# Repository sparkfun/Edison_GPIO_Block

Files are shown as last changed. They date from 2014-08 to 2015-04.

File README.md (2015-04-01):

SparkFun Edison GPIO Breakout
=============================

SparkFun Edison GPIO Breakout

[*SparkFun Edison GPIO Breakout(DEV-13038)*](https://www.sparkfun.com/products/13038)

The GPIO Breakout is a simple breakout board to bring the GPIO from the Intel Edison to the user.  Bread board friendly, the GPIO provides level-shifted access to all basic GPIO, PWM, and UART2. GPIO may be set to VSYS or 3.3v levels. The GPIO Breakout also provides access to all three power rails found on the Intel Edison.  3.3v, 1.8v, VSYS, and GND are accessable for bread board prototyping.

Repository Contents
-------------------
* **/Hardware** - All Eagle design files (.brd, .sch)
* **/Production** - TEst bed files and production panel files

License Information
-------------------

The hardware is released under [Creative Commons ShareAlike 4.0 International](https://creativecommons.org/licenses/by-sa/4.0/).
The code is beerware; if you see me (or any other SparkFun employee) at the local, and you've found our code helpful, please buy us a round!

Distributed as-is; no warranty is given.

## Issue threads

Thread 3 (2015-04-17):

Fritzing Component?

rwaldron, 2015-04-17:
Is there any chance of adding a fritzing component for this block?

ToniCorinne, 2015-04-17:
@HelloTechie Could we get this added in to the Fritzing repo?

HelloTechie, 2015-04-17:
Let me put it on the list! The main connector won't be usable, but the pins would be. Is that okay?

ToniCorinne, 2015-04-17:
I don't have any problem with that personally.

HelloTechie, 2015-04-17:
Awesome! Will post when completed. :)

HelloTechie, 2015-06-12:
Reorganized Fritzing and this part can be found here: https://github.com/sparkfun/Fritzing_Parts/commit/9dca354bc97bc871e642fe05f99ecdcb9647cb63

Sorry for the wait!

Closed 2015-06-12.

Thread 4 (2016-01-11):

Issues Enabling PWM Pins

mikekberg, 2016-01-11:
Is there any documentation regarding enabling the PWM pins? I've tried enabling the GPIO pin and PWM channel for the given pin and I'm not able to get PWM to work. Is there a requirement to set pin muxing like the ardino breakout board?

ShawnHymel, 2016-01-11:
If you are using MRAA, you can use the PWM class: http://iotdk.intel.com/docs/master/mraa/classmraa_1_1_pwm.html

mikekberg, 2016-01-11:
How can I push to these using echo's to the filesystem? I think I might just be missing the command to set the Pinmode to PWM. How is that done?

ShawnHymel, 2016-01-11:
You'll have to set the pin mode. Here's the best documentation I've found: http://www.emutexlabs.com/project/215-intel-edison-gpio-pin-multiplexing-guide

mikekberg, 2016-01-12:
I'm using the following:

echo mode1 > /sys/kernel/debug/gpio_debug/gpio12/current_pinmux
echo 0 > /sys/class/pwm/pwmchip0/export
echo 20000000 > /sys/class/pwm/pwmchip0/pwm0/period
echo 1080000 > /sys/class/pwm/pwmchip0/pwm0/duty_cycle
echo 1 > /sys/class/pwm/pwmchip0/pwm0/enable

this should in theory push a signal down the PWM0 channel. The previous post is documentation for the ardino breakout board which requires setting a number of pins to disable internal pull up resistors and set the direction of the pin. These pins are not present with the GPIO block (write errors when I try writing to them).

ShawnHymel, 2016-01-12:
I don't have an Edison in front of me right now to test this, but for now, see if [this article](https://theiotlearninginitiative.gitbooks.io/inteledison/content/documentation/PinMuxing.html) or [this post](https://communities.intel.com/thread/45986?start=0&) helps at all.

Also, how are you measuring PWM? The level shifters on the GPIO block have a hard time driving any amount of current (even 1 or 2 mA). Are you using a scope or connecting an LED, etc.?

mhord, 2016-01-12:
I've sweated through this myself, quite a bit. I feel like I eventually got it working but it's been awhile.

Your best bet is probably to [look at how Intel's mraa library](https://github.com/intel-iot-devkit/mraa/blob/master/src/pwm/pwm.c) does it; they're basically just constructing strings and pushing them into the files. I'm not saying it'll be easy; there are a lot of layers of conditionals and #define statements to dig through, but it will at least give you some idea of where you're headed.

mikekberg, 2016-01-12:
Thanks, That helps out a ton. I'll do some digging and see if I can post a solution for anyone else looking.

mikekberg, 2016-01-13:
So I've taken a look through the source and the code I posted above does work I was initially running on lower current and like @ShawnHymel commented about the current was too low to see an LED turn on.

Looks like the GPIO board follows the same mux'ing requirements the ardino breakout board uses. Thanks everyone!

AbhiKag, 2016-04-22:
Hey, I seem to be stuck at the same spot. Could you tell me how you worked around this (any config/hardware setup) ?

mikekberg, 2016-04-22:
Yes! I did get this going. I'll dig up the source code and post it. Are you looking to do it through bash shell or are you writing code? what language?

mikekberg, 2016-04-22:
This worked for me from bash

echo 12 > /sys/class/gpio/export
echo out > /sys/class/gpio/gpio12/direction
echo mode1 > /sys/kernel/debug/gpio_debug/gpio12/current_pinmux
echo 0 > /sys/class/pwm/pwmchip0/export
echo 20000000 > /sys/class/pwm/pwmchip0/pwm0/period
echo 1080000 > /sys/class/pwm/pwmchip0/pwm0/duty_cycle
echo 1 > /sys/class/pwm/pwmchip0/pwm0/enable

AbhiKag, 2016-04-22:
Thanks for the prompt response!
I will try this out.
For me, the sparkfun gpio board pwm pins are giving out a very low current (almost unusable).
Did you experience something similar, and if so, is there any solution?
I am open to any option, bash or c++! MRAA doesn't seem to be working though (maybe a platform recognition issue?) .

ShawnHymel, 2016-04-22:
In its normal operation, the TXB0108 (the level shifter on the GPIO Block) cannot source more than about 5 mA, which is barely enough to power an LED. I generally use a transistor to connect LEDs to the GPIO Block, like in [this example](https://learn.sparkfun.com/tutorials/installing-libmraa-on-ubilinux-for-edison#the-circuit).

Closed 2016-01-13.

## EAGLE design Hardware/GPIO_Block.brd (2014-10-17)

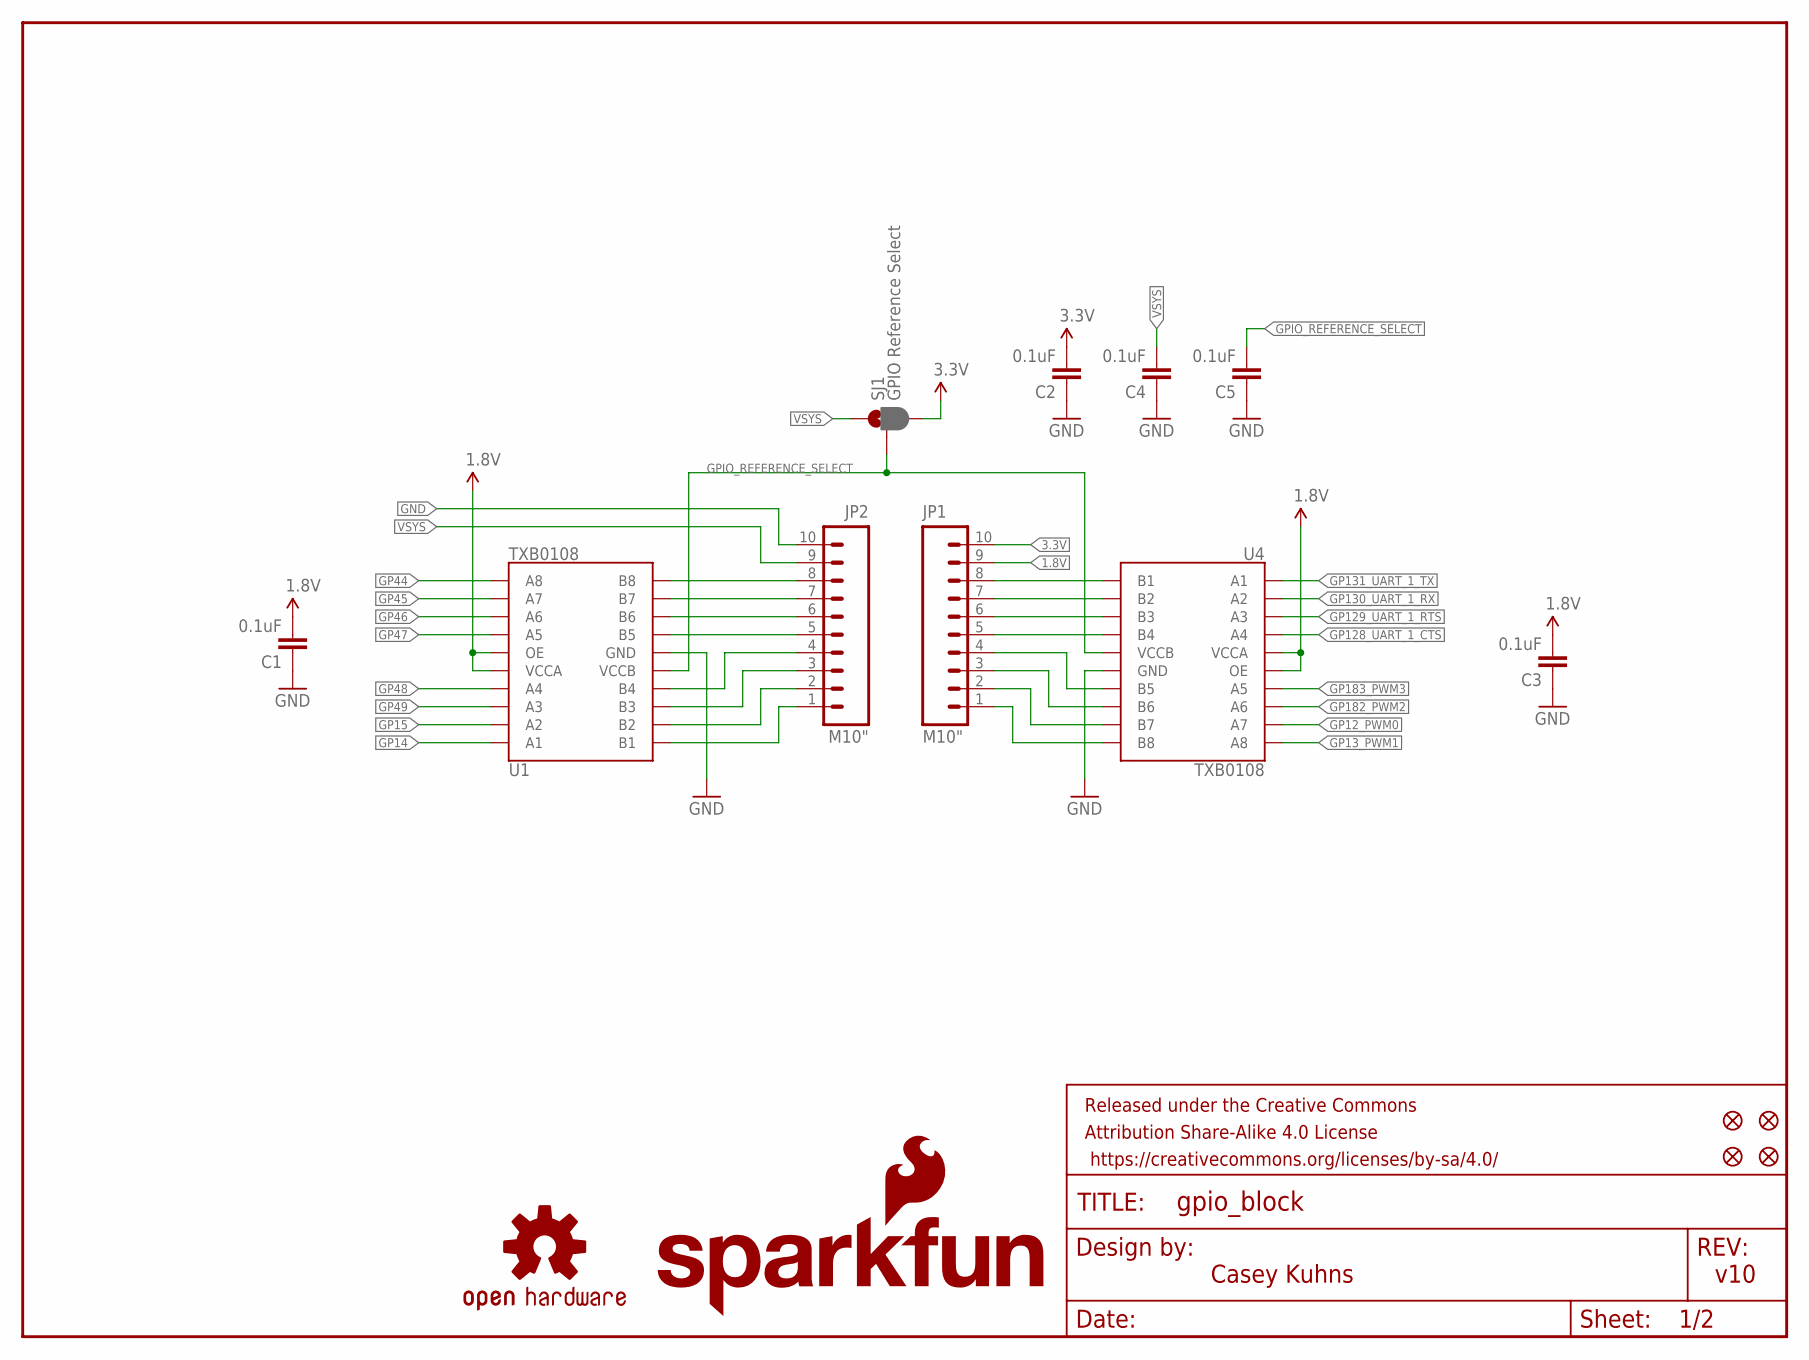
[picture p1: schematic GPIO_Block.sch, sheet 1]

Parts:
C1, C2, C3, C4, C5: 0.1uF; 0603-CAP
FID1, FID2, FID3, FID4: FIDUCIAL1X2; FIDUCIAL-1X2
FRAME1: FRAME-LETTER; CREATIVE_COMMONS
JP1, JP2: M10"; 1X10
LOGO1: OSHW-LOGOS; OSHW-LOGO-S
LOGO4: SFE_LOGO_NAME_FLAME.1_INCH; SFE_LOGO_NAME_FLAME_.1
SJ1: GPIO Reference Select; PAD-JUMPER-3-2OF3_NC_BY_PASTE_YES_SILK_FULL_BOX
U1, U4: TXB0108; UFDFN-20

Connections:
1.8V: C1.2, C3.2, JP1.9, U1.5 (VCCA), U1.6 (OE), U4.5 (VCCA), U4.6 (OE); also elsewhere on the board
3.3V: C2.2, JP1.10, SJ1.3; also elsewhere on the board
GND: C1.1, C2.1, C3.1, C4.1, C5.1, JP2.10, U1.15 (GND), U4.15 (GND); also elsewhere on the board
GP12_PWM0: U4.9 (A7); also elsewhere on the board
GP13_PWM1: U4.10 (A8); also elsewhere on the board
GP14: U1.1 (A1); also elsewhere on the board
GP15: U1.2 (A2); also elsewhere on the board
GP44: U1.10 (A8); also elsewhere on the board
GP45: U1.9 (A7); also elsewhere on the board
GP46: U1.8 (A6); also elsewhere on the board
GP47: U1.7 (A5); also elsewhere on the board
GP48: U1.4 (A4); also elsewhere on the board
GP49: U1.3 (A3); also elsewhere on the board
GP128_UART_1_CTS: U4.4 (A4); also elsewhere on the board
GP129_UART_1_RTS: U4.3 (A3); also elsewhere on the board
GP130_UART_1_RX: U4.2 (A2); also elsewhere on the board
GP131_UART_1_TX: U4.1 (A1); also elsewhere on the board
GP182_PWM2: U4.8 (A6); also elsewhere on the board
GP183_PWM3: U4.7 (A5); also elsewhere on the board
GPIO_REFERENCE_SELECT: C5.2, SJ1.2, U1.16 (VCCB), U4.16 (VCCB)
unnamed: JP2.8, U1.11 (B8)
unnamed: JP2.7, U1.12 (B7)
unnamed: JP2.6, U1.13 (B6)
unnamed: JP2.5, U1.14 (B5)
unnamed: JP2.4, U1.17 (B4)
unnamed: JP2.3, U1.18 (B3)
unnamed: JP2.2, U1.19 (B2)
unnamed: JP2.1, U1.20 (B1)
unnamed: JP1.4, U4.14 (B5)
unnamed: JP1.3, U4.13 (B6)
unnamed: JP1.2, U4.12 (B7)
unnamed: JP1.1, U4.11 (B8)
unnamed: JP1.5, U4.17 (B4)
unnamed: JP1.6, U4.18 (B3)
unnamed: JP1.7, U4.19 (B2)
unnamed: JP1.8, U4.20 (B1)
VSYS: C4.2, JP2.9, SJ1.1; also elsewhere on the board

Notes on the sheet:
v10
Casey Kuhns

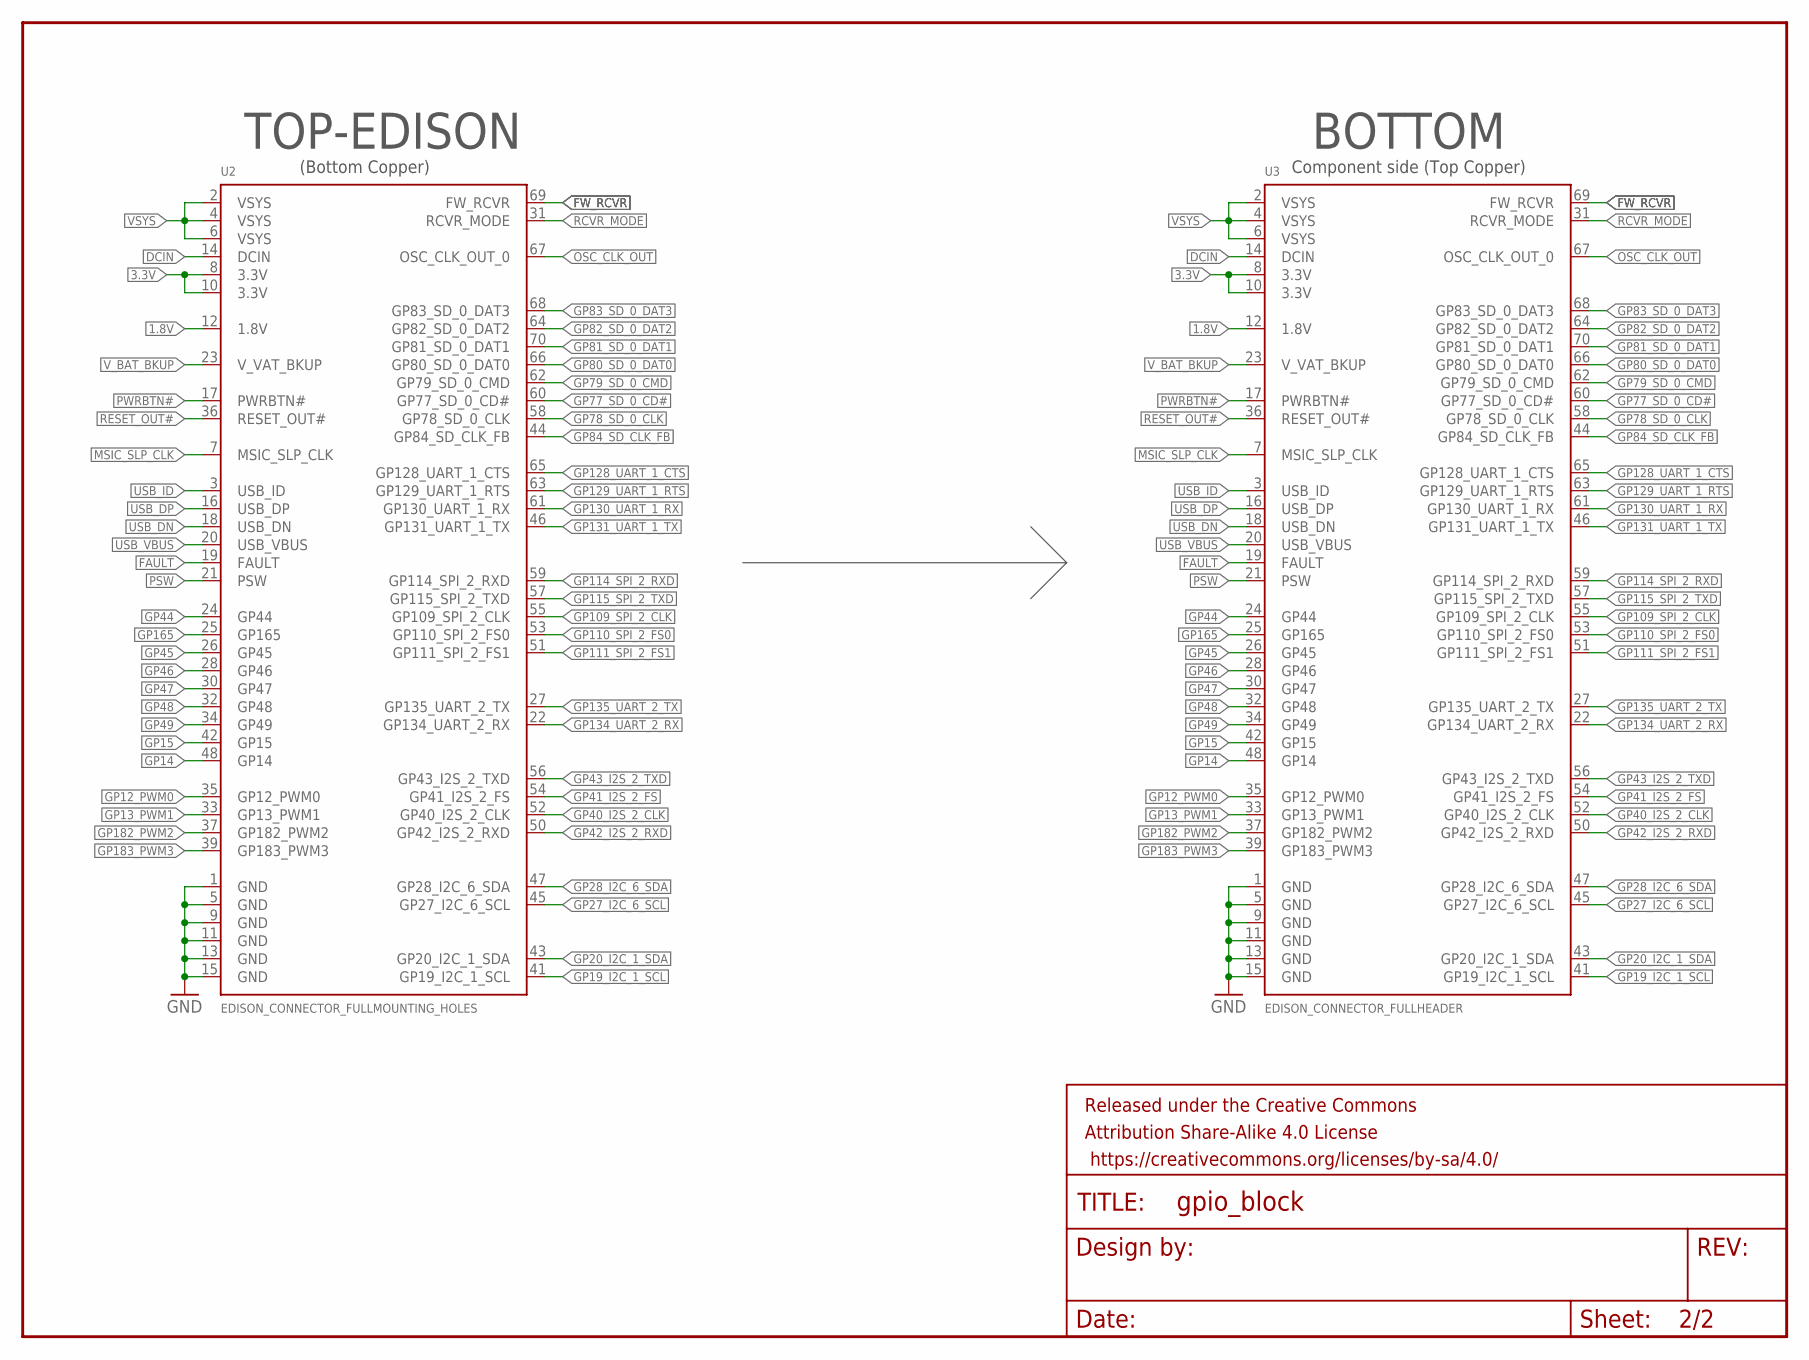
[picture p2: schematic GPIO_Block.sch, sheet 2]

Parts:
FRAME2: FRAME-LETTER; CREATIVE_COMMONS
U2: EDISON_CONNECTOR_FULLMOUNTING_HOLES; EDISON_DAUGHTER
U3: EDISON_CONNECTOR_FULLHEADER; DF40C-70DP-0.4(51)

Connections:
1.8V: U2.12 (1.8V), U3.12 (1.8V); also elsewhere on the board
3.3V: U2.8 (3.3V), U2.10 (3.3V), U3.8 (3.3V), U3.10 (3.3V); also elsewhere on the board
DCIN: U2.14 (DCIN), U3.14 (DCIN)
FAULT: U2.19 (FAULT), U3.19 (FAULT)
FW_RCVR: U2.69 (FW_RCVR), U3.69 (FW_RCVR)
GND: U2.1 (GND), U2.5 (GND), U2.9 (GND), U2.11 (GND), U2.13 (GND), U2.15 (GND), U3.1 (GND), U3.5 (GND), U3.9 (GND), U3.11 (GND), U3.13 (GND), U3.15 (GND); also elsewhere on the board
GP12_PWM0: U2.35 (GP12_PWM0), U3.35 (GP12_PWM0); also elsewhere on the board
GP13_PWM1: U2.33 (GP13_PWM1), U3.33 (GP13_PWM1); also elsewhere on the board
GP14: U2.48 (GP14), U3.48 (GP14); also elsewhere on the board
GP15: U2.42 (GP15), U3.42 (GP15); also elsewhere on the board
GP19_I2C_1_SCL: U2.41 (GP19_I2C_1_SCL), U3.41 (GP19_I2C_1_SCL)
GP20_I2C_1_SDA: U2.43 (GP20_I2C_1_SDA), U3.43 (GP20_I2C_1_SDA)
GP27_I2C_6_SCL: U2.45 (GP27_I2C_6_SCL), U3.45 (GP27_I2C_6_SCL)
GP28_I2C_6_SDA: U2.47 (GP28_I2C_6_SDA), U3.47 (GP28_I2C_6_SDA)
GP40_I2S_2_CLK: U2.52 (GP40_I2S_2_CLK), U3.52 (GP40_I2S_2_CLK)
GP41_I2S_2_FS: U2.54 (GP41_I2S_2_FS), U3.54 (GP41_I2S_2_FS)
GP42_I2S_2_RXD: U2.50 (GP42_I2S_2_RXD), U3.50 (GP42_I2S_2_RXD)
GP43_I2S_2_TXD: U2.56 (GP43_I2S_2_TXD), U3.56 (GP43_I2S_2_TXD)
GP44: U2.24 (GP44), U3.24 (GP44); also elsewhere on the board
GP45: U2.26 (GP45), U3.26 (GP45); also elsewhere on the board
GP46: U2.28 (GP46), U3.28 (GP46); also elsewhere on the board
GP47: U2.30 (GP47), U3.30 (GP47); also elsewhere on the board
GP48: U2.32 (GP48), U3.32 (GP48); also elsewhere on the board
GP49: U2.34 (GP49), U3.34 (GP49); also elsewhere on the board
GP77_SD_0_CD#: U2.60 (GP77_SD_0_CD#), U3.60 (GP77_SD_0_CD#)
GP78_SD_0_CLK: U2.58 (GP78_SD_0_CLK), U3.58 (GP78_SD_0_CLK)
GP79_SD_0_CMD: U2.62 (GP79_SD_0_CMD), U3.62 (GP79_SD_0_CMD)
GP80_SD_0_DAT0: U2.66 (GP80_SD_0_DAT0), U3.66 (GP80_SD_0_DAT0)
GP81_SD_0_DAT1: U2.70 (GP81_SD_0_DAT1), U3.70 (GP81_SD_0_DAT1)
GP82_SD_0_DAT2: U2.64 (GP82_SD_0_DAT2), U3.64 (GP82_SD_0_DAT2)
GP83_SD_0_DAT3: U2.68 (GP83_SD_0_DAT3), U3.68 (GP83_SD_0_DAT3)
GP84_SD_CLK_FB: U2.44 (GP84_SD_CLK_FB), U3.44 (GP84_SD_CLK_FB)
GP109_SPI_2_CLK: U2.55 (GP109_SPI_2_CLK), U3.55 (GP109_SPI_2_CLK)
GP110_SPI_2_FS0: U2.53 (GP110_SPI_2_FS0), U3.53 (GP110_SPI_2_FS0)
GP111_SPI_2_FS1: U2.51 (GP111_SPI_2_FS1), U3.51 (GP111_SPI_2_FS1)
GP114_SPI_2_RXD: U2.59 (GP114_SPI_2_RXD), U3.59 (GP114_SPI_2_RXD)
GP115_SPI_2_TXD: U2.57 (GP115_SPI_2_TXD), U3.57 (GP115_SPI_2_TXD)
GP128_UART_1_CTS: U2.65 (GP128_UART_1_CTS), U3.65 (GP128_UART_1_CTS); also elsewhere on the board
GP129_UART_1_RTS: U2.63 (GP129_UART_1_RTS), U3.63 (GP129_UART_1_RTS); also elsewhere on the board
GP130_UART_1_RX: U2.61 (GP130_UART_1_RX), U3.61 (GP130_UART_1_RX); also elsewhere on the board
GP131_UART_1_TX: U2.46 (GP131_UART_1_TX), U3.46 (GP131_UART_1_TX); also elsewhere on the board
GP134_UART_2_RX: U2.22 (GP134_UART_2_RX), U3.22 (GP134_UART_2_RX)
GP135_UART_2_TX: U2.27 (GP135_UART_2_TX), U3.27 (GP135_UART_2_TX)
GP165: U2.25 (GP165), U3.25 (GP165)
GP182_PWM2: U2.37 (GP182_PWM2), U3.37 (GP182_PWM2); also elsewhere on the board
GP183_PWM3: U2.39 (GP183_PWM3), U3.39 (GP183_PWM3); also elsewhere on the board
MSIC_SLP_CLK: U2.7 (MSIC_SLP_CLK), U3.7 (MSIC_SLP_CLK)
OSC_CLK_OUT: U2.67 (OSC_CLK_OUT_0), U3.67 (OSC_CLK_OUT_0)
PSW: U2.21 (PSW), U3.21 (PSW)
PWRBTN#: U2.17 (PWRBTN#), U3.17 (PWRBTN#)
RCVR_MODE: U2.31 (RCVR_MODE), U3.31 (RCVR_MODE)
RESET_OUT#: U2.36 (RESET_OUT#), U3.36 (RESET_OUT#)
USB_DN: U2.18 (USB_DN), U3.18 (USB_DN)
USB_DP: U2.16 (USB_DP), U3.16 (USB_DP)
USB_ID: U2.3 (USB_ID), U3.3 (USB_ID)
USB_VBUS: U2.20 (USB_VBUS), U3.20 (USB_VBUS)
VSYS: U2.2 (VSYS), U2.4 (VSYS), U2.6 (VSYS), U3.2 (VSYS), U3.4 (VSYS), U3.6 (VSYS); also elsewhere on the board
V_BAT_BKUP: U2.23 (V_VAT_BKUP), U3.23 (V_VAT_BKUP)

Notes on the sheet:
TOP-EDISON
BOTTOM
Component side (Top Copper)
(Bottom Copper)

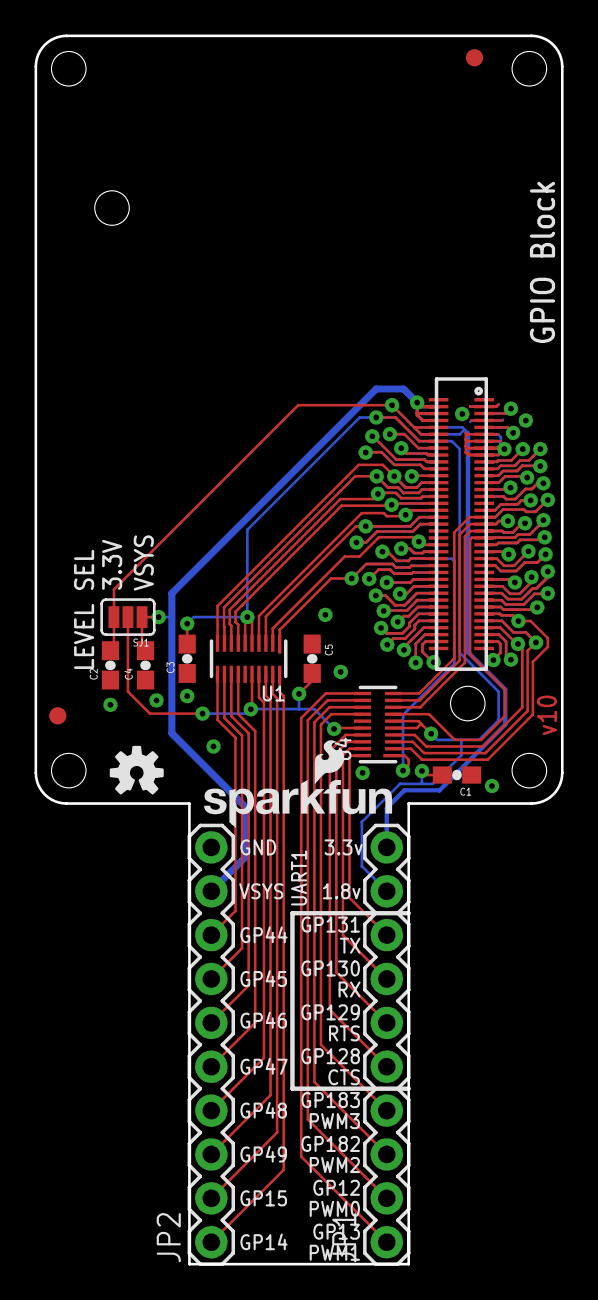
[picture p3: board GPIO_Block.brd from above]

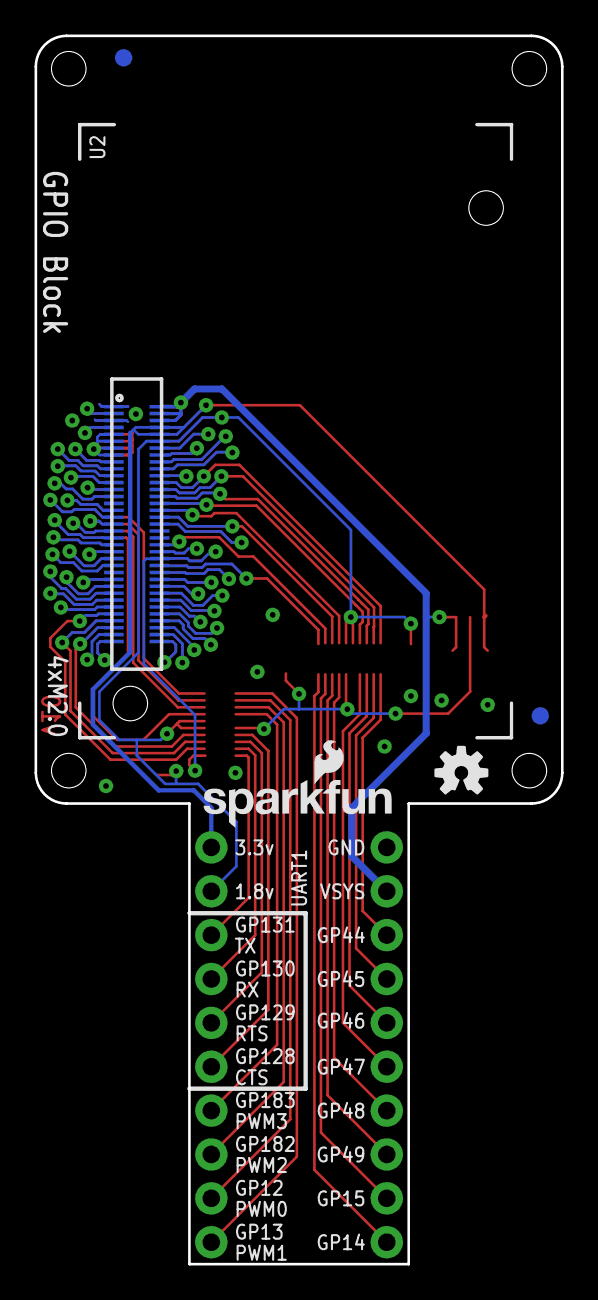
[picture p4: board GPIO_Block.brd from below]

Board: 2 copper layers, 30.5 x 71.1 mm, 22 parts (6 on the bottom side), 75 nets.

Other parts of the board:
LOGO2: OSHW-LOGOS; OSHW-LOGO-S
LOGO3: SFE_LOGO_NAME_FLAME.1_INCH; SFE_LOGO_NAME_FLAME_.1

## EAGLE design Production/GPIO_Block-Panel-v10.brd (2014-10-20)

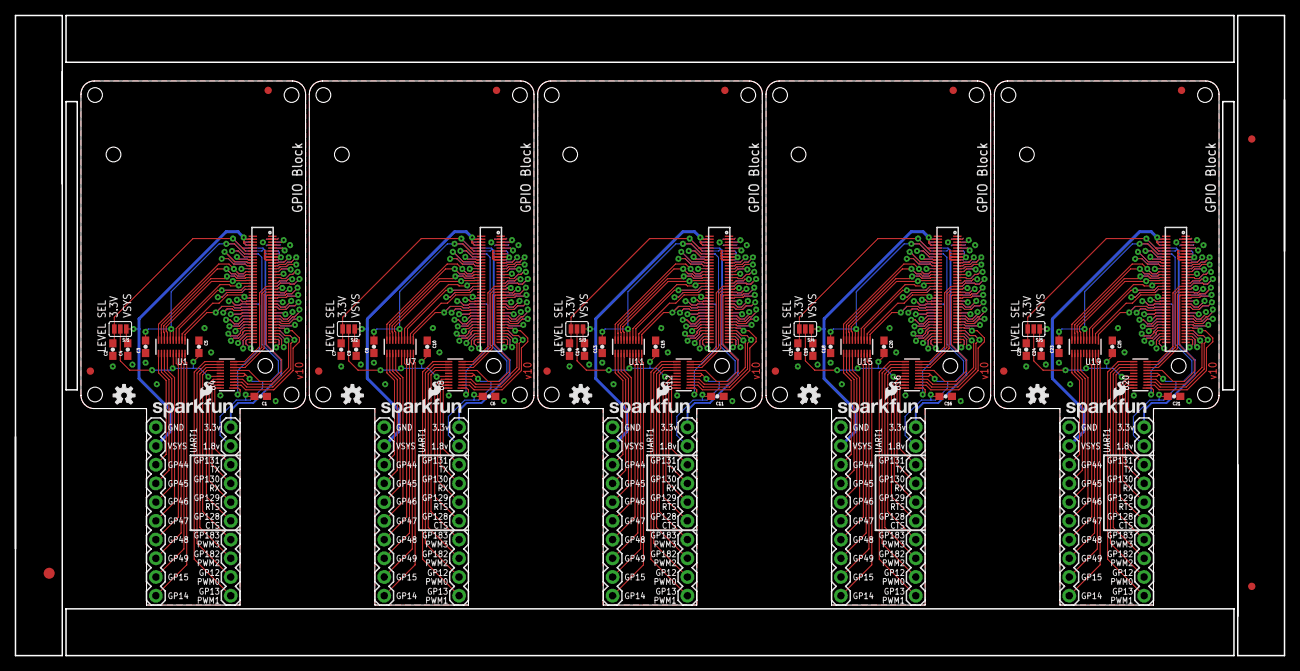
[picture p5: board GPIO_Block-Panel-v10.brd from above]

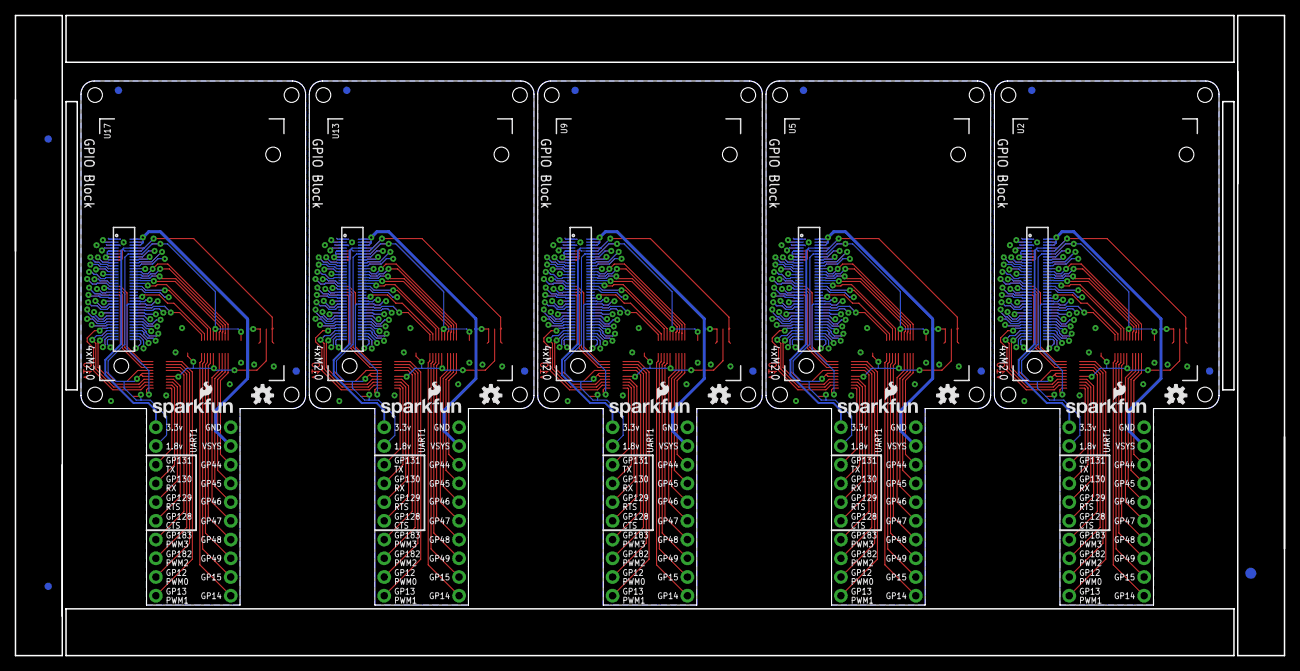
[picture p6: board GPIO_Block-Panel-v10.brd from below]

Board: 2 copper layers, 172.2 x 86.9 mm, 106 parts (33 on the bottom side), 375 nets.

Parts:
C1, C2, C3, C4, C5, C6, C7, C8, C9, C10, C11, C12, C13, C14, C15, C16, C17, C18, C19, C20, C21, C22, C23, C24, C25: 0.1uF; 0603-CAP
E$1, E$2: FIDUCIAL-1.5X3
E$3, E$4, E$5, E$6: FIDUCIAL-1X2
FID1, FID2, FID3, FID4, FID5, FID6, FID7, FID8, FID9, FID10, FID11, FID12, FID13, FID14, FID15, FID16, FID17, FID18, FID19, FID20: FIDUCIAL1X2; FIDUCIAL-1X2
JP1, JP2, JP3, JP4, JP5, JP6, JP7, JP8, JP9, JP10: M10"; 1X10
LOGO1, LOGO2, LOGO5, LOGO7, LOGO9, LOGO11, LOGO13, LOGO15, LOGO17, LOGO19: OSHW-LOGOS; OSHW-LOGO-S
LOGO3, LOGO4, LOGO6, LOGO8, LOGO10, LOGO12, LOGO14, LOGO16, LOGO18, LOGO20: SFE_LOGO_NAME_FLAME.1_INCH; SFE_LOGO_NAME_FLAME_.1
SJ1, SJ2, SJ3, SJ4, SJ5: GPIO Reference Select; PAD-JUMPER-3-2OF3_NC_BY_PASTE_YES_SILK_FULL_BOX
U1, U4, U7, U8, U11, U12, U15, U16, U19, U20: TXB0108; UFDFN-20
U2, U5, U9, U13, U17: EDISON_CONNECTOR_FULLMOUNTING_HOLES; EDISON_DAUGHTER
U3, U6, U10, U14, U18: EDISON_CONNECTOR_FULLHEADER; DF40C-70DP-0.4(51)

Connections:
1.8V: C1.2, C3.2, JP1.9, U1.5, U1.6, U2.12, U3.12, U4.5, U4.6
1.8V1: C6.2, C8.2, JP3.9, U5.12, U6.12, U7.5, U7.6, U8.5, U8.6
1.8V2: C11.2, C13.2, JP5.9, U9.12, U10.12, U11.5, U11.6, U12.5, U12.6
1.8V3: C16.2, C18.2, JP7.9, U13.12, U14.12, U15.5, U15.6, U16.5, U16.6
1.8V4: C21.2, C23.2, JP9.9, U17.12, U18.12, U19.5, U19.6, U20.5, U20.6
3.3V: C2.2, JP1.10, SJ1.3, U2.8, U2.10, U3.8, U3.10
3.3V1: C7.2, JP3.10, SJ2.3, U5.8, U5.10, U6.8, U6.10
3.3V2: C12.2, JP5.10, SJ3.3, U9.8, U9.10, U10.8, U10.10
3.3V3: C17.2, JP7.10, SJ4.3, U13.8, U13.10, U14.8, U14.10
3.3V4: C22.2, JP9.10, SJ5.3, U17.8, U17.10, U18.8, U18.10
DCIN: U2.14, U3.14
DCIN1: U5.14, U6.14
DCIN2: U9.14, U10.14
DCIN3: U13.14, U14.14
DCIN4: U17.14, U18.14
FAULT: U2.19, U3.19
FAULT1: U5.19, U6.19
FAULT2: U9.19, U10.19
FAULT3: U13.19, U14.19
FAULT4: U17.19, U18.19
FW_RCVR: U2.69, U3.69
FW_RCVR1: U5.69, U6.69
FW_RCVR2: U9.69, U10.69
FW_RCVR3: U13.69, U14.69
FW_RCVR4: U17.69, U18.69
GND: C1.1, C2.1, C3.1, C4.1, C5.1, JP2.10, U1.15, U2.1, U2.5, U2.9, U2.11, U2.13, U2.15, U3.1, U3.5, U3.9, U3.11, U3.13, U3.15, U4.15
GND1: C6.1, C7.1, C8.1, C9.1, C10.1, JP4.10, U5.1, U5.5, U5.9, U5.11, U5.13, U5.15, U6.1, U6.5, U6.9, U6.11, U6.13, U6.15, U7.15, U8.15
GND2: C11.1, C12.1, C13.1, C14.1, C15.1, JP6.10, U9.1, U9.5, U9.9, U9.11, U9.13, U9.15, U10.1, U10.5, U10.9, U10.11, U10.13, U10.15, U11.15, U12.15
GND3: C16.1, C17.1, C18.1, C19.1, C20.1, JP8.10, U13.1, U13.5, U13.9, U13.11, U13.13, U13.15, U14.1, U14.5, U14.9, U14.11, U14.13, U14.15, U15.15, U16.15
GND4: C21.1, C22.1, C23.1, C24.1, C25.1, JP10.10, U17.1, U17.5, U17.9, U17.11, U17.13, U17.15, U18.1, U18.5, U18.9, U18.11, U18.13, U18.15, U19.15, U20.15
GP1: U5.48, U6.48, U7.1
GP2: U5.42, U6.42, U7.2
GP3: U5.34, U6.34, U7.3
GP4: U5.32, U6.32, U7.4
GP5: U5.30, U6.30, U7.7
GP6: U5.28, U6.28, U7.8
GP7: U5.26, U6.26, U7.9
GP8: U5.25, U6.25
GP9: U5.24, U6.24, U7.10
GP10: U9.48, U10.48, U11.1
GP11: U9.42, U10.42, U11.2
GP12: U9.34, U10.34, U11.3
GP12_PWM0: U2.35, U3.35, U4.9
GP12_PWM1: U5.35, U6.35, U8.9
GP12_PWM2: U9.35, U10.35, U12.9
GP12_PWM3: U13.35, U14.35, U16.9
GP12_PWM4: U17.35, U18.35, U20.9
GP13: U9.32, U10.32, U11.4
GP13_PWM1: U2.33, U3.33, U4.10
GP13_PWM2: U5.33, U6.33, U8.10
GP13_PWM3: U9.33, U10.33, U12.10
GP13_PWM4: U13.33, U14.33, U16.10
GP13_PWM5: U17.33, U18.33, U20.10
GP14: U1.1, U2.48, U3.48
GP15: U1.2, U2.42, U3.42
GP16: U9.30, U10.30, U11.7
GP17: U9.28, U10.28, U11.8
GP18: U9.26, U10.26, U11.9
GP19: U9.25, U10.25
GP19_I2C_1_SCL: U2.41, U3.41
GP19_I2C_1_SCL1: U5.41, U6.41
GP19_I2C_1_SCL2: U9.41, U10.41
GP19_I2C_1_SCL3: U13.41, U14.41
GP19_I2C_1_SCL4: U17.41, U18.41
GP20: U9.24, U10.24, U11.10
GP20_I2C_1_SDA: U2.43, U3.43
GP20_I2C_1_SDA1: U5.43, U6.43
GP20_I2C_1_SDA2: U9.43, U10.43
GP20_I2C_1_SDA3: U13.43, U14.43
GP20_I2C_1_SDA4: U17.43, U18.43
GP21: U13.48, U14.48, U15.1
GP22: U13.42, U14.42, U15.2
GP23: U13.34, U14.34, U15.3
GP24: U13.32, U14.32, U15.4
GP25: U13.30, U14.30, U15.7
GP26: U13.28, U14.28, U15.8
GP27: U13.26, U14.26, U15.9
GP27_I2C_6_SCL: U2.45, U3.45
GP27_I2C_6_SCL1: U5.45, U6.45
GP27_I2C_6_SCL2: U9.45, U10.45
GP27_I2C_6_SCL3: U13.45, U14.45
GP27_I2C_6_SCL4: U17.45, U18.45
GP28: U13.25, U14.25
GP28_I2C_6_SDA: U2.47, U3.47
GP28_I2C_6_SDA1: U5.47, U6.47
GP28_I2C_6_SDA2: U9.47, U10.47
GP28_I2C_6_SDA3: U13.47, U14.47
GP28_I2C_6_SDA4: U17.47, U18.47
GP29: U13.24, U14.24, U15.10
GP30: U17.48, U18.48, U19.1
GP31: U17.42, U18.42, U19.2
GP32: U17.34, U18.34, U19.3
GP33: U17.32, U18.32, U19.4
GP34: U17.30, U18.30, U19.7
GP35: U17.28, U18.28, U19.8
GP36: U17.26, U18.26, U19.9
GP37: U17.25, U18.25
GP38: U17.24, U18.24, U19.10
GP40_I2S_2_CLK: U2.52, U3.52
GP40_I2S_2_CLK1: U5.52, U6.52
GP40_I2S_2_CLK2: U9.52, U10.52
GP40_I2S_2_CLK3: U13.52, U14.52
GP40_I2S_2_CLK4: U17.52, U18.52
GP41_I2S_2_FS: U2.54, U3.54
GP41_I2S_2_FS1: U5.54, U6.54
GP41_I2S_2_FS2: U9.54, U10.54
GP41_I2S_2_FS3: U13.54, U14.54
GP41_I2S_2_FS4: U17.54, U18.54
GP42_I2S_2_RXD: U2.50, U3.50
GP42_I2S_2_RXD1: U5.50, U6.50
GP42_I2S_2_RXD2: U9.50, U10.50
GP42_I2S_2_RXD3: U13.50, U14.50
GP42_I2S_2_RXD4: U17.50, U18.50
GP43_I2S_2_TXD: U2.56, U3.56
GP43_I2S_2_TXD1: U5.56, U6.56
GP43_I2S_2_TXD2: U9.56, U10.56
GP43_I2S_2_TXD3: U13.56, U14.56
GP43_I2S_2_TXD4: U17.56, U18.56
GP44: U1.10, U2.24, U3.24
GP45: U1.9, U2.26, U3.26
GP46: U1.8, U2.28, U3.28
GP47: U1.7, U2.30, U3.30
GP48: U1.4, U2.32, U3.32
GP49: U1.3, U2.34, U3.34
GP77_SD_0_CD#: U2.60, U3.60
GP77_SD_0_CD#1: U5.60, U6.60
GP77_SD_0_CD#2: U9.60, U10.60
GP77_SD_0_CD#3: U13.60, U14.60
GP77_SD_0_CD#4: U17.60, U18.60
GP78_SD_0_CLK: U2.58, U3.58
GP78_SD_0_CLK1: U5.58, U6.58
GP78_SD_0_CLK2: U9.58, U10.58
GP78_SD_0_CLK3: U13.58, U14.58
GP78_SD_0_CLK4: U17.58, U18.58
GP79_SD_0_CMD: U2.62, U3.62
GP79_SD_0_CMD1: U5.62, U6.62
GP79_SD_0_CMD2: U9.62, U10.62
GP79_SD_0_CMD3: U13.62, U14.62
GP79_SD_0_CMD4: U17.62, U18.62
GP80_SD_0_DAT0: U2.66, U3.66
GP80_SD_0_DAT1: U5.66, U6.66
GP80_SD_0_DAT2: U9.66, U10.66
GP80_SD_0_DAT3: U13.66, U14.66
GP80_SD_0_DAT4: U17.66, U18.66
GP81_SD_0_DAT1: U2.70, U3.70
GP81_SD_0_DAT2: U5.70, U6.70
GP81_SD_0_DAT3: U9.70, U10.70
GP81_SD_0_DAT4: U13.70, U14.70
GP81_SD_0_DAT5: U17.70, U18.70
GP82_SD_0_DAT1: U5.64, U6.64
GP82_SD_0_DAT2: U2.64, U3.64
GP82_SD_0_DAT3: U9.64, U10.64
GP82_SD_0_DAT4: U13.64, U14.64
GP82_SD_0_DAT5: U17.64, U18.64
GP83_SD_0_DAT1: U5.68, U6.68
GP83_SD_0_DAT2: U9.68, U10.68
GP83_SD_0_DAT3: U2.68, U3.68
GP83_SD_0_DAT4: U13.68, U14.68
GP83_SD_0_DAT5: U17.68, U18.68
GP84_SD_CLK_FB: U2.44, U3.44
GP84_SD_CLK_FB1: U5.44, U6.44
GP84_SD_CLK_FB2: U9.44, U10.44
GP84_SD_CLK_FB3: U13.44, U14.44
GP84_SD_CLK_FB4: U17.44, U18.44
GP109_SPI_2_CLK: U2.55, U3.55
GP109_SPI_2_CLK1: U5.55, U6.55
GP109_SPI_2_CLK2: U9.55, U10.55
GP109_SPI_2_CLK3: U13.55, U14.55
GP109_SPI_2_CLK4: U17.55, U18.55
GP110_SPI_2_FS0: U2.53, U3.53
GP110_SPI_2_FS1: U5.53, U6.53
GP110_SPI_2_FS2: U9.53, U10.53
GP110_SPI_2_FS3: U13.53, U14.53
GP110_SPI_2_FS4: U17.53, U18.53
GP111_SPI_2_FS1: U2.51, U3.51
GP111_SPI_2_FS2: U5.51, U6.51
GP111_SPI_2_FS3: U9.51, U10.51
GP111_SPI_2_FS4: U13.51, U14.51
GP111_SPI_2_FS5: U17.51, U18.51
GP114_SPI_2_RXD: U2.59, U3.59
GP114_SPI_2_RXD1: U5.59, U6.59
GP114_SPI_2_RXD2: U9.59, U10.59
GP114_SPI_2_RXD3: U13.59, U14.59
GP114_SPI_2_RXD4: U17.59, U18.59
GP115_SPI_2_TXD: U2.57, U3.57
GP115_SPI_2_TXD1: U5.57, U6.57
GP115_SPI_2_TXD2: U9.57, U10.57
GP115_SPI_2_TXD3: U13.57, U14.57
GP115_SPI_2_TXD4: U17.57, U18.57
GP128_UART_1_CTS: U2.65, U3.65, U4.4
GP128_UART_1_CTS1: U5.65, U6.65, U8.4
GP128_UART_1_CTS2: U9.65, U10.65, U12.4
GP128_UART_1_CTS3: U13.65, U14.65, U16.4
GP128_UART_1_CTS4: U17.65, U18.65, U20.4
GP129_UART_1_RTS: U2.63, U3.63, U4.3
GP129_UART_1_RTS1: U5.63, U6.63, U8.3
GP129_UART_1_RTS2: U9.63, U10.63, U12.3
GP129_UART_1_RTS3: U13.63, U14.63, U16.3
GP129_UART_1_RTS4: U17.63, U18.63, U20.3
GP130_UART_1_RX: U2.61, U3.61, U4.2
GP130_UART_1_RX1: U5.61, U6.61, U8.2
GP130_UART_1_RX2: U9.61, U10.61, U12.2
GP130_UART_1_RX3: U13.61, U14.61, U16.2
GP130_UART_1_RX4: U17.61, U18.61, U20.2
GP131_UART_1_TX: U2.46, U3.46, U4.1
GP131_UART_1_TX1: U5.46, U6.46, U8.1
GP131_UART_1_TX2: U9.46, U10.46, U12.1
GP131_UART_1_TX3: U13.46, U14.46, U16.1
GP131_UART_1_TX4: U17.46, U18.46, U20.1
GP134_UART_2_RX: U2.22, U3.22
GP134_UART_2_RX1: U5.22, U6.22
GP134_UART_2_RX2: U9.22, U10.22
GP134_UART_2_RX3: U13.22, U14.22
GP134_UART_2_RX4: U17.22, U18.22
GP135_UART_2_TX: U2.27, U3.27
GP135_UART_2_TX1: U5.27, U6.27
GP135_UART_2_TX2: U9.27, U10.27
GP135_UART_2_TX3: U13.27, U14.27
GP135_UART_2_TX4: U17.27, U18.27
GP165: U2.25, U3.25
GP182_PWM1: U5.37, U6.37, U8.8
GP182_PWM2: U2.37, U3.37, U4.8
GP182_PWM3: U9.37, U10.37, U12.8
GP182_PWM4: U13.37, U14.37, U16.8
GP182_PWM5: U17.37, U18.37, U20.8
GP183_PWM1: U5.39, U6.39, U8.7
GP183_PWM2: U9.39, U10.39, U12.7
GP183_PWM3: U2.39, U3.39, U4.7
GP183_PWM4: U13.39, U14.39, U16.7
GP183_PWM5: U17.39, U18.39, U20.7
GPIO_REFERENCE_SELECT: C5.2, SJ1.2, U1.16, U4.16
GPIO_REFERENCE_SELECT1: C10.2, SJ2.2, U7.16, U8.16
GPIO_REFERENCE_SELECT2: C15.2, SJ3.2, U11.16, U12.16
GPIO_REFERENCE_SELECT3: C20.2, SJ4.2, U15.16, U16.16
GPIO_REFERENCE_SELECT4: C25.2, SJ5.2, U19.16, U20.16
MSIC_SLP_CLK: U2.7, U3.7
MSIC_SLP_CLK1: U5.7, U6.7
MSIC_SLP_CLK2: U9.7, U10.7
MSIC_SLP_CLK3: U13.7, U14.7
MSIC_SLP_CLK4: U17.7, U18.7
unnamed: JP2.8, U1.11
unnamed: JP2.7, U1.12
unnamed: JP2.6, U1.13
unnamed: JP2.5, U1.14
unnamed: JP2.4, U1.17
unnamed: JP2.3, U1.18
unnamed: JP2.2, U1.19
unnamed: JP2.1, U1.20
unnamed: JP4.8, U7.11
unnamed: JP4.7, U7.12
unnamed: JP1.4, U4.14
unnamed: JP1.3, U4.13
unnamed: JP1.2, U4.12
unnamed: JP1.1, U4.11
unnamed: JP1.5, U4.17
unnamed: JP1.6, U4.18
unnamed: JP1.7, U4.19
unnamed: JP1.8, U4.20
unnamed: JP4.6, U7.13
unnamed: JP4.5, U7.14
unnamed: JP4.4, U7.17
unnamed: JP4.3, U7.18
unnamed: JP4.2, U7.19
unnamed: JP4.1, U7.20
unnamed: JP3.5, U8.17
unnamed: JP3.6, U8.18
unnamed: JP3.7, U8.19
unnamed: JP3.8, U8.20
unnamed: JP3.4, U8.14
unnamed: JP3.3, U8.13
unnamed: JP3.2, U8.12
unnamed: JP3.1, U8.11
unnamed: JP6.8, U11.11
unnamed: JP6.7, U11.12
unnamed: JP6.6, U11.13
unnamed: JP6.5, U11.14
unnamed: JP6.4, U11.17
unnamed: JP6.3, U11.18
unnamed: JP6.2, U11.19
unnamed: JP6.1, U11.20
unnamed: JP5.5, U12.17
unnamed: JP5.6, U12.18
unnamed: JP5.7, U12.19
unnamed: JP5.8, U12.20
unnamed: JP5.4, U12.14
unnamed: JP5.3, U12.13
unnamed: JP5.2, U12.12
unnamed: JP5.1, U12.11
unnamed: JP8.8, U15.11
unnamed: JP8.7, U15.12
unnamed: JP8.6, U15.13
unnamed: JP8.5, U15.14
unnamed: JP8.4, U15.17
unnamed: JP8.3, U15.18
unnamed: JP8.2, U15.19
unnamed: JP8.1, U15.20
unnamed: JP7.5, U16.17
unnamed: JP7.6, U16.18
unnamed: JP7.7, U16.19
unnamed: JP7.8, U16.20
unnamed: JP7.4, U16.14
unnamed: JP7.3, U16.13
unnamed: JP7.2, U16.12
unnamed: JP7.1, U16.11
unnamed: JP10.8, U19.11
unnamed: JP10.7, U19.12
unnamed: JP10.6, U19.13
unnamed: JP10.5, U19.14
unnamed: JP10.4, U19.17
unnamed: JP10.3, U19.18
unnamed: JP10.2, U19.19
unnamed: JP10.1, U19.20
unnamed: JP9.5, U20.17
unnamed: JP9.6, U20.18
unnamed: JP9.7, U20.19
unnamed: JP9.8, U20.20
unnamed: JP9.4, U20.14
unnamed: JP9.3, U20.13
unnamed: JP9.2, U20.12
unnamed: JP9.1, U20.11
OSC_CLK_OUT: U2.67, U3.67
OSC_CLK_OUT1: U5.67, U6.67
OSC_CLK_OUT2: U9.67, U10.67
OSC_CLK_OUT3: U13.67, U14.67
OSC_CLK_OUT4: U17.67, U18.67
PSW: U2.21, U3.21
PSW1: U5.21, U6.21
PSW2: U9.21, U10.21
PSW3: U13.21, U14.21
PSW4: U17.21, U18.21
PWRBTN#: U2.17, U3.17
PWRBTN#1: U5.17, U6.17
PWRBTN#2: U9.17, U10.17
PWRBTN#3: U13.17, U14.17
PWRBTN#4: U17.17, U18.17
RCVR_MODE: U2.31, U3.31
RCVR_MODE1: U5.31, U6.31
RCVR_MODE2: U9.31, U10.31
RCVR_MODE3: U13.31, U14.31
RCVR_MODE4: U17.31, U18.31
RESET_OUT#: U2.36, U3.36
RESET_OUT#1: U5.36, U6.36
RESET_OUT#2: U9.36, U10.36
RESET_OUT#3: U13.36, U14.36
RESET_OUT#4: U17.36, U18.36
USB_DN: U2.18, U3.18
USB_DN1: U5.18, U6.18
USB_DN2: U9.18, U10.18
USB_DN3: U13.18, U14.18
USB_DN4: U17.18, U18.18
USB_DP: U2.16, U3.16
USB_DP1: U5.16, U6.16
USB_DP2: U9.16, U10.16
USB_DP3: U13.16, U14.16
USB_DP4: U17.16, U18.16
USB_ID: U2.3, U3.3
USB_ID1: U5.3, U6.3
USB_ID2: U9.3, U10.3
USB_ID3: U13.3, U14.3
USB_ID4: U17.3, U18.3
USB_VBUS: U2.20, U3.20
USB_VBUS1: U5.20, U6.20
USB_VBUS2: U9.20, U10.20
USB_VBUS3: U13.20, U14.20
USB_VBUS4: U17.20, U18.20
VSYS: C4.2, JP2.9, SJ1.1, U2.2, U2.4, U2.6, U3.2, U3.4, U3.6
VSYS1: C9.2, JP4.9, SJ2.1, U5.2, U5.4, U5.6, U6.2, U6.4, U6.6
VSYS2: C14.2, JP6.9, SJ3.1, U9.2, U9.4, U9.6, U10.2, U10.4, U10.6
VSYS3: C19.2, JP8.9, SJ4.1, U13.2, U13.4, U13.6, U14.2, U14.4, U14.6
VSYS4: C24.2, JP10.9, SJ5.1, U17.2, U17.4, U17.6, U18.2, U18.4, U18.6
V_BAT_BKUP: U2.23, U3.23
V_BAT_BKUP1: U5.23, U6.23
V_BAT_BKUP2: U9.23, U10.23
V_BAT_BKUP3: U13.23, U14.23
V_BAT_BKUP4: U17.23, U18.23

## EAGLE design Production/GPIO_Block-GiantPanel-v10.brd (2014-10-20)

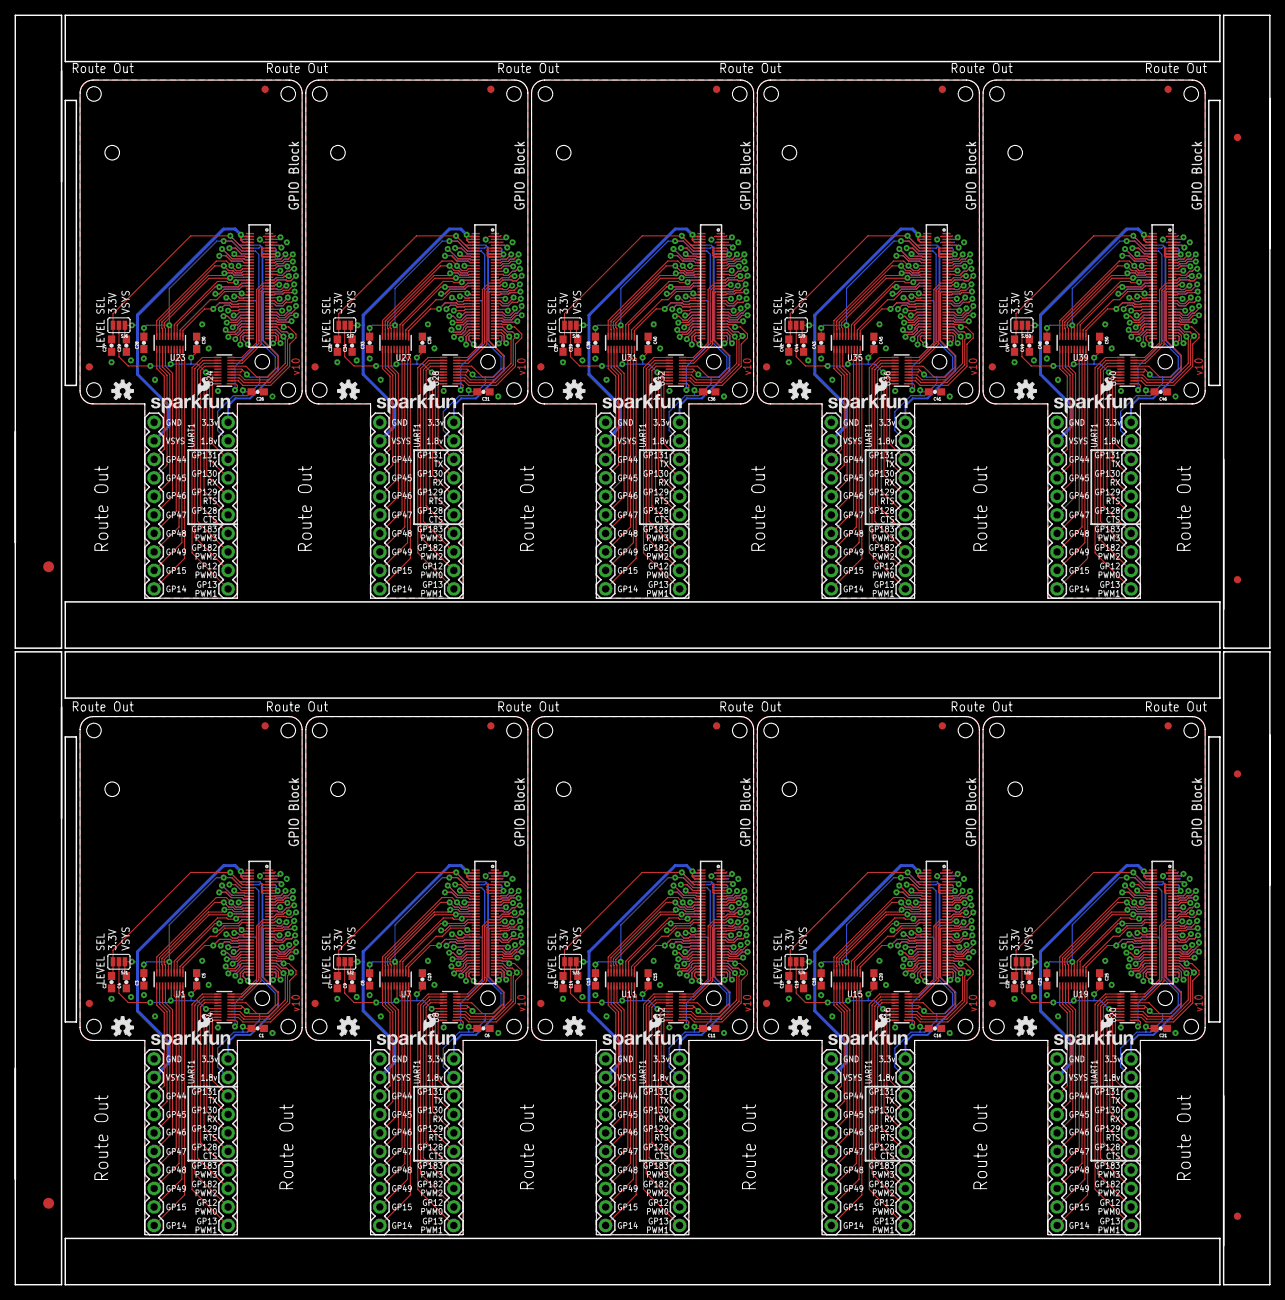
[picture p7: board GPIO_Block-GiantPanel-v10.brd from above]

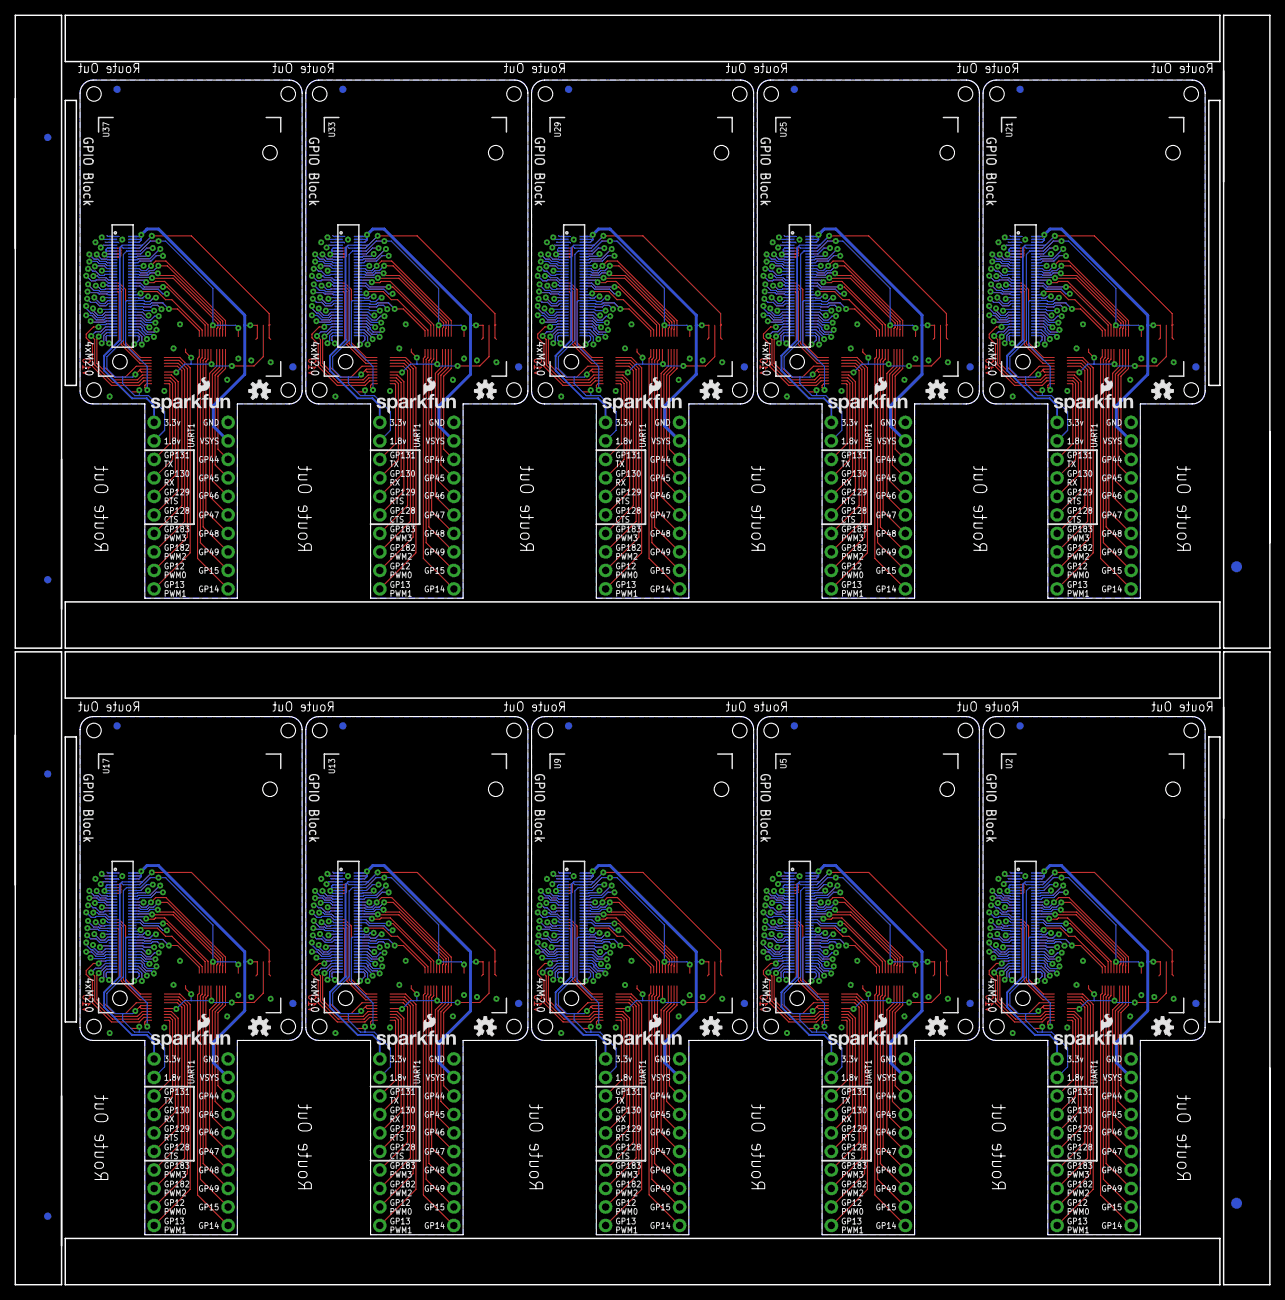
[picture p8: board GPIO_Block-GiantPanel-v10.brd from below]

Board: 2 copper layers, 172.2 x 174.2 mm, 212 parts (66 on the bottom side), 750 nets.

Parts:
C1, C2, C3, C4, C5, C6, C7, C8, C9, C10, C11, C12, C13, C14, C15, C16, C17, C18, C19, C20, C21, C22, C23, C24, C25, C26, C27, C28, C29, C30, C31, C32, C33, C34, C35, C36, C37, C38, C39, C40, C41, C42, C43, C44, C45, C46, C47, C48, C49, C50: 0.1uF; 0603-CAP
E$1, E$2, E$9, E$10: FIDUCIAL-1.5X3
E$3, E$4, E$5, E$6, E$7, E$8, E$11, E$12: FIDUCIAL-1X2
FID1, FID2, FID3, FID4, FID5, FID6, FID7, FID8, FID9, FID10, FID11, FID12, FID13, FID14, FID15, FID16, FID17, FID18, FID19, FID20, FID21, FID22, FID23, FID24, FID25, FID26, FID27, FID28, FID29, FID30, FID31, FID32, FID33, FID34, FID35, FID36, FID37, FID38, FID39, FID40: FIDUCIAL1X2; FIDUCIAL-1X2
JP1, JP2, JP3, JP4, JP5, JP6, JP7, JP8, JP9, JP10, JP11, JP12, JP13, JP14, JP15, JP16, JP17, JP18, JP19, JP20: M10"; 1X10
LOGO1, LOGO2, LOGO5, LOGO7, LOGO9, LOGO11, LOGO13, LOGO15, LOGO17, LOGO19, LOGO21, LOGO23, LOGO25, LOGO27, LOGO29, LOGO31, LOGO33, LOGO35, LOGO37, LOGO39: OSHW-LOGOS; OSHW-LOGO-S
LOGO3, LOGO4, LOGO6, LOGO8, LOGO10, LOGO12, LOGO14, LOGO16, LOGO18, LOGO20, LOGO22, LOGO24, LOGO26, LOGO28, LOGO30, LOGO32, LOGO34, LOGO36, LOGO38, LOGO40: SFE_LOGO_NAME_FLAME.1_INCH; SFE_LOGO_NAME_FLAME_.1
SJ1, SJ2, SJ3, SJ4, SJ5, SJ6, SJ7, SJ8, SJ9, SJ10: GPIO Reference Select; PAD-JUMPER-3-2OF3_NC_BY_PASTE_YES_SILK_FULL_BOX
U1, U4, U7, U8, U11, U12, U15, U16, U19, U20, U23, U24, U27, U28, U31, U32, U35, U36, U39, U40: TXB0108; UFDFN-20
U2, U5, U9, U13, U17, U21, U25, U29, U33, U37: EDISON_CONNECTOR_FULLMOUNTING_HOLES; EDISON_DAUGHTER
U3, U6, U10, U14, U18, U22, U26, U30, U34, U38: EDISON_CONNECTOR_FULLHEADER; DF40C-70DP-0.4(51)

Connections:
1.8V: C1.2, C3.2, JP1.9, U1.5, U1.6, U2.12, U3.12, U4.5, U4.6
1.8V1: C6.2, C8.2, JP3.9, U5.12, U6.12, U7.5, U7.6, U8.5, U8.6
1.8V2: C11.2, C13.2, JP5.9, U9.12, U10.12, U11.5, U11.6, U12.5, U12.6
1.8V3: C16.2, C18.2, JP7.9, U13.12, U14.12, U15.5, U15.6, U16.5, U16.6
1.8V4: C21.2, C23.2, JP9.9, U17.12, U18.12, U19.5, U19.6, U20.5, U20.6
1.8V5: C26.2, C28.2, JP11.9, U21.12, U22.12, U23.5, U23.6, U24.5, U24.6
1.8V6: C31.2, C33.2, JP13.9, U25.12, U26.12, U27.5, U27.6, U28.5, U28.6
1.8V7: C36.2, C38.2, JP15.9, U29.12, U30.12, U31.5, U31.6, U32.5, U32.6
1.8V8: C41.2, C43.2, JP17.9, U33.12, U34.12, U35.5, U35.6, U36.5, U36.6
1.8V9: C46.2, C48.2, JP19.9, U37.12, U38.12, U39.5, U39.6, U40.5, U40.6
3.3V: C2.2, JP1.10, SJ1.3, U2.8, U2.10, U3.8, U3.10
3.3V1: C7.2, JP3.10, SJ2.3, U5.8, U5.10, U6.8, U6.10
3.3V2: C12.2, JP5.10, SJ3.3, U9.8, U9.10, U10.8, U10.10
3.3V3: C17.2, JP7.10, SJ4.3, U13.8, U13.10, U14.8, U14.10
3.3V4: C22.2, JP9.10, SJ5.3, U17.8, U17.10, U18.8, U18.10
3.3V5: C27.2, JP11.10, SJ6.3, U21.8, U21.10, U22.8, U22.10
3.3V6: C32.2, JP13.10, SJ7.3, U25.8, U25.10, U26.8, U26.10
3.3V7: C37.2, JP15.10, SJ8.3, U29.8, U29.10, U30.8, U30.10
3.3V8: C42.2, JP17.10, SJ9.3, U33.8, U33.10, U34.8, U34.10
3.3V9: C47.2, JP19.10, SJ10.3, U37.8, U37.10, U38.8, U38.10
DCIN: U2.14, U3.14
DCIN1: U5.14, U6.14
DCIN2: U9.14, U10.14
DCIN3: U13.14, U14.14
DCIN4: U17.14, U18.14
DCIN5: U21.14, U22.14
DCIN6: U25.14, U26.14
DCIN7: U29.14, U30.14
DCIN8: U33.14, U34.14
DCIN9: U37.14, U38.14
FAULT: U2.19, U3.19
FAULT1: U5.19, U6.19
FAULT2: U9.19, U10.19
FAULT3: U13.19, U14.19
FAULT4: U17.19, U18.19
FAULT5: U21.19, U22.19
FAULT6: U25.19, U26.19
FAULT7: U29.19, U30.19
FAULT8: U33.19, U34.19
FAULT9: U37.19, U38.19
FW_RCVR: U2.69, U3.69
FW_RCVR1: U5.69, U6.69
FW_RCVR2: U9.69, U10.69
FW_RCVR3: U13.69, U14.69
FW_RCVR4: U17.69, U18.69
FW_RCVR5: U21.69, U22.69
FW_RCVR6: U25.69, U26.69
FW_RCVR7: U29.69, U30.69
FW_RCVR8: U33.69, U34.69
FW_RCVR9: U37.69, U38.69
GND: C1.1, C2.1, C3.1, C4.1, C5.1, JP2.10, U1.15, U2.1, U2.5, U2.9, U2.11, U2.13, U2.15, U3.1, U3.5, U3.9, U3.11, U3.13, U3.15, U4.15
GND1: C6.1, C7.1, C8.1, C9.1, C10.1, JP4.10, U5.1, U5.5, U5.9, U5.11, U5.13, U5.15, U6.1, U6.5, U6.9, U6.11, U6.13, U6.15, U7.15, U8.15
GND2: C11.1, C12.1, C13.1, C14.1, C15.1, JP6.10, U9.1, U9.5, U9.9, U9.11, U9.13, U9.15, U10.1, U10.5, U10.9, U10.11, U10.13, U10.15, U11.15, U12.15
GND3: C16.1, C17.1, C18.1, C19.1, C20.1, JP8.10, U13.1, U13.5, U13.9, U13.11, U13.13, U13.15, U14.1, U14.5, U14.9, U14.11, U14.13, U14.15, U15.15, U16.15
GND4: C21.1, C22.1, C23.1, C24.1, C25.1, JP10.10, U17.1, U17.5, U17.9, U17.11, U17.13, U17.15, U18.1, U18.5, U18.9, U18.11, U18.13, U18.15, U19.15, U20.15
GND5: C26.1, C27.1, C28.1, C29.1, C30.1, JP12.10, U21.1, U21.5, U21.9, U21.11, U21.13, U21.15, U22.1, U22.5, U22.9, U22.11, U22.13, U22.15, U23.15, U24.15
GND6: C31.1, C32.1, C33.1, C34.1, C35.1, JP14.10, U25.1, U25.5, U25.9, U25.11, U25.13, U25.15, U26.1, U26.5, U26.9, U26.11, U26.13, U26.15, U27.15, U28.15
GND7: C36.1, C37.1, C38.1, C39.1, C40.1, JP16.10, U29.1, U29.5, U29.9, U29.11, U29.13, U29.15, U30.1, U30.5, U30.9, U30.11, U30.13, U30.15, U31.15, U32.15
GND8: C41.1, C42.1, C43.1, C44.1, C45.1, JP18.10, U33.1, U33.5, U33.9, U33.11, U33.13, U33.15, U34.1, U34.5, U34.9, U34.11, U34.13, U34.15, U35.15, U36.15
GND9: C46.1, C47.1, C48.1, C49.1, C50.1, JP20.10, U37.1, U37.5, U37.9, U37.11, U37.13, U37.15, U38.1, U38.5, U38.9, U38.11, U38.13, U38.15, U39.15, U40.15
GP1: U5.48, U6.48, U7.1
GP2: U5.42, U6.42, U7.2
GP3: U5.34, U6.34, U7.3
GP4: U5.32, U6.32, U7.4
GP5: U5.30, U6.30, U7.7
GP6: U5.28, U6.28, U7.8
GP7: U5.26, U6.26, U7.9
GP8: U5.25, U6.25
GP9: U5.24, U6.24, U7.10
GP10: U9.48, U10.48, U11.1
GP11: U9.42, U10.42, U11.2
GP12: U9.34, U10.34, U11.3
GP12_PWM0: U2.35, U3.35, U4.9
GP12_PWM1: U5.35, U6.35, U8.9
GP12_PWM2: U9.35, U10.35, U12.9
GP12_PWM3: U13.35, U14.35, U16.9
GP12_PWM4: U17.35, U18.35, U20.9
GP12_PWM5: U21.35, U22.35, U24.9
GP12_PWM6: U25.35, U26.35, U28.9
GP12_PWM7: U29.35, U30.35, U32.9
GP12_PWM8: U33.35, U34.35, U36.9
GP12_PWM9: U37.35, U38.35, U40.9
GP13: U9.32, U10.32, U11.4
GP13_PWM1: U2.33, U3.33, U4.10
GP13_PWM2: U5.33, U6.33, U8.10
GP13_PWM3: U9.33, U10.33, U12.10
GP13_PWM4: U13.33, U14.33, U16.10
GP13_PWM5: U17.33, U18.33, U20.10
GP13_PWM6: U21.33, U22.33, U24.10
GP13_PWM7: U25.33, U26.33, U28.10
GP13_PWM8: U29.33, U30.33, U32.10
GP13_PWM9: U33.33, U34.33, U36.10
GP13_PWM10: U37.33, U38.33, U40.10
GP14: U1.1, U2.48, U3.48
GP15: U1.2, U2.42, U3.42
GP16: U9.30, U10.30, U11.7
GP17: U9.28, U10.28, U11.8
GP18: U9.26, U10.26, U11.9
GP19: U9.25, U10.25
GP19_I2C_1_SCL: U2.41, U3.41
GP19_I2C_1_SCL1: U5.41, U6.41
GP19_I2C_1_SCL2: U9.41, U10.41
GP19_I2C_1_SCL3: U13.41, U14.41
GP19_I2C_1_SCL4: U17.41, U18.41
GP19_I2C_1_SCL5: U21.41, U22.41
GP19_I2C_1_SCL6: U25.41, U26.41
GP19_I2C_1_SCL7: U29.41, U30.41
GP19_I2C_1_SCL8: U33.41, U34.41
GP19_I2C_1_SCL9: U37.41, U38.41
GP20: U9.24, U10.24, U11.10
GP20_I2C_1_SDA: U2.43, U3.43
GP20_I2C_1_SDA1: U5.43, U6.43
GP20_I2C_1_SDA2: U9.43, U10.43
GP20_I2C_1_SDA3: U13.43, U14.43
GP20_I2C_1_SDA4: U17.43, U18.43
GP20_I2C_1_SDA5: U21.43, U22.43
GP20_I2C_1_SDA6: U25.43, U26.43
GP20_I2C_1_SDA7: U29.43, U30.43
GP20_I2C_1_SDA8: U33.43, U34.43
GP20_I2C_1_SDA9: U37.43, U38.43
GP21: U13.48, U14.48, U15.1
GP22: U13.42, U14.42, U15.2
GP23: U13.34, U14.34, U15.3
GP24: U13.32, U14.32, U15.4
GP25: U13.30, U14.30, U15.7
GP26: U13.28, U14.28, U15.8
GP27: U13.26, U14.26, U15.9
GP27_I2C_6_SCL: U2.45, U3.45
GP27_I2C_6_SCL1: U5.45, U6.45
GP27_I2C_6_SCL2: U9.45, U10.45
GP27_I2C_6_SCL3: U13.45, U14.45
GP27_I2C_6_SCL4: U17.45, U18.45
GP27_I2C_6_SCL5: U21.45, U22.45
GP27_I2C_6_SCL6: U25.45, U26.45
GP27_I2C_6_SCL7: U29.45, U30.45
GP27_I2C_6_SCL8: U33.45, U34.45
GP27_I2C_6_SCL9: U37.45, U38.45
GP28: U13.25, U14.25
GP28_I2C_6_SDA: U2.47, U3.47
GP28_I2C_6_SDA1: U5.47, U6.47
GP28_I2C_6_SDA2: U9.47, U10.47
GP28_I2C_6_SDA3: U13.47, U14.47
GP28_I2C_6_SDA4: U17.47, U18.47
GP28_I2C_6_SDA5: U21.47, U22.47
GP28_I2C_6_SDA6: U25.47, U26.47
GP28_I2C_6_SDA7: U29.47, U30.47
GP28_I2C_6_SDA8: U33.47, U34.47
GP28_I2C_6_SDA9: U37.47, U38.47
GP29: U13.24, U14.24, U15.10
GP30: U17.48, U18.48, U19.1
GP31: U17.42, U18.42, U19.2
GP32: U17.34, U18.34, U19.3
GP33: U17.32, U18.32, U19.4
GP34: U17.30, U18.30, U19.7
GP35: U17.28, U18.28, U19.8
GP36: U17.26, U18.26, U19.9
GP37: U17.25, U18.25
GP38: U17.24, U18.24, U19.10
GP39: U21.48, U22.48, U23.1
GP40: U21.42, U22.42, U23.2
GP40_I2S_2_CLK: U2.52, U3.52
GP40_I2S_2_CLK1: U5.52, U6.52
GP40_I2S_2_CLK2: U9.52, U10.52
GP40_I2S_2_CLK3: U13.52, U14.52
GP40_I2S_2_CLK4: U17.52, U18.52
GP40_I2S_2_CLK5: U21.52, U22.52
GP40_I2S_2_CLK6: U25.52, U26.52
GP40_I2S_2_CLK7: U29.52, U30.52
GP40_I2S_2_CLK8: U33.52, U34.52
GP40_I2S_2_CLK9: U37.52, U38.52
GP41: U21.34, U22.34, U23.3
GP41_I2S_2_FS: U2.54, U3.54
GP41_I2S_2_FS1: U5.54, U6.54
GP41_I2S_2_FS2: U9.54, U10.54
GP41_I2S_2_FS3: U13.54, U14.54
GP41_I2S_2_FS4: U17.54, U18.54
GP41_I2S_2_FS5: U21.54, U22.54
GP41_I2S_2_FS6: U25.54, U26.54
GP41_I2S_2_FS7: U29.54, U30.54
GP41_I2S_2_FS8: U33.54, U34.54
GP41_I2S_2_FS9: U37.54, U38.54
GP42: U21.32, U22.32, U23.4
GP42_I2S_2_RXD: U2.50, U3.50
GP42_I2S_2_RXD1: U5.50, U6.50
GP42_I2S_2_RXD2: U9.50, U10.50
GP42_I2S_2_RXD3: U13.50, U14.50
GP42_I2S_2_RXD4: U17.50, U18.50
GP42_I2S_2_RXD5: U21.50, U22.50
GP42_I2S_2_RXD6: U25.50, U26.50
GP42_I2S_2_RXD7: U29.50, U30.50
GP42_I2S_2_RXD8: U33.50, U34.50
GP42_I2S_2_RXD9: U37.50, U38.50
GP43: U21.30, U22.30, U23.7
GP43_I2S_2_TXD: U2.56, U3.56
GP43_I2S_2_TXD1: U5.56, U6.56
GP43_I2S_2_TXD2: U9.56, U10.56
GP43_I2S_2_TXD3: U13.56, U14.56
GP43_I2S_2_TXD4: U17.56, U18.56
GP43_I2S_2_TXD5: U21.56, U22.56
GP43_I2S_2_TXD6: U25.56, U26.56
GP43_I2S_2_TXD7: U29.56, U30.56
GP43_I2S_2_TXD8: U33.56, U34.56
GP43_I2S_2_TXD9: U37.56, U38.56
GP44: U1.10, U2.24, U3.24
GP45: U1.9, U2.26, U3.26
GP46: U1.8, U2.28, U3.28
GP47: U1.7, U2.30, U3.30
GP48: U1.4, U2.32, U3.32
GP49: U1.3, U2.34, U3.34
GP50: U21.28, U22.28, U23.8
GP51: U21.26, U22.26, U23.9
GP52: U21.25, U22.25
GP53: U21.24, U22.24, U23.10
GP54: U25.48, U26.48, U27.1
GP55: U25.42, U26.42, U27.2
GP56: U25.34, U26.34, U27.3
GP57: U25.32, U26.32, U27.4
GP58: U25.30, U26.30, U27.7
GP59: U25.28, U26.28, U27.8
GP60: U25.26, U26.26, U27.9
GP61: U25.25, U26.25
GP62: U25.24, U26.24, U27.10
GP63: U29.48, U30.48, U31.1
GP64: U29.42, U30.42, U31.2
GP65: U29.34, U30.34, U31.3
GP66: U29.32, U30.32, U31.4
GP67: U29.30, U30.30, U31.7
GP68: U29.28, U30.28, U31.8
GP69: U29.26, U30.26, U31.9
GP70: U29.25, U30.25
GP71: U29.24, U30.24, U31.10
GP72: U33.48, U34.48, U35.1
GP73: U33.42, U34.42, U35.2
GP74: U33.34, U34.34, U35.3
GP75: U33.32, U34.32, U35.4
GP76: U33.30, U34.30, U35.7
GP77: U33.28, U34.28, U35.8
GP77_SD_0_CD#: U2.60, U3.60
GP77_SD_0_CD#1: U5.60, U6.60
GP77_SD_0_CD#2: U9.60, U10.60
GP77_SD_0_CD#3: U13.60, U14.60
GP77_SD_0_CD#4: U17.60, U18.60
GP77_SD_0_CD#5: U21.60, U22.60
GP77_SD_0_CD#6: U25.60, U26.60
GP77_SD_0_CD#7: U29.60, U30.60
GP77_SD_0_CD#8: U33.60, U34.60
GP77_SD_0_CD#9: U37.60, U38.60
GP78: U33.26, U34.26, U35.9
GP78_SD_0_CLK: U2.58, U3.58
GP78_SD_0_CLK1: U5.58, U6.58
GP78_SD_0_CLK2: U9.58, U10.58
GP78_SD_0_CLK3: U13.58, U14.58
GP78_SD_0_CLK4: U17.58, U18.58
GP78_SD_0_CLK5: U21.58, U22.58
GP78_SD_0_CLK6: U25.58, U26.58
GP78_SD_0_CLK7: U29.58, U30.58
GP78_SD_0_CLK8: U33.58, U34.58
GP78_SD_0_CLK9: U37.58, U38.58
GP79: U33.25, U34.25
GP79_SD_0_CMD: U2.62, U3.62
GP79_SD_0_CMD1: U5.62, U6.62
GP79_SD_0_CMD2: U9.62, U10.62
GP79_SD_0_CMD3: U13.62, U14.62
GP79_SD_0_CMD4: U17.62, U18.62
GP79_SD_0_CMD5: U21.62, U22.62
GP79_SD_0_CMD6: U25.62, U26.62
GP79_SD_0_CMD7: U29.62, U30.62
GP79_SD_0_CMD8: U33.62, U34.62
GP79_SD_0_CMD9: U37.62, U38.62
GP80: U33.24, U34.24, U35.10
GP80_SD_0_DAT0: U2.66, U3.66
GP80_SD_0_DAT1: U5.66, U6.66
GP80_SD_0_DAT2: U9.66, U10.66
GP80_SD_0_DAT3: U13.66, U14.66
GP80_SD_0_DAT4: U17.66, U18.66
GP80_SD_0_DAT5: U21.66, U22.66
GP80_SD_0_DAT6: U25.66, U26.66
GP80_SD_0_DAT7: U29.66, U30.66
GP80_SD_0_DAT8: U33.66, U34.66
GP80_SD_0_DAT9: U37.66, U38.66
GP81: U37.48, U38.48, U39.1
GP81_SD_0_DAT1: U2.70, U3.70
GP81_SD_0_DAT2: U5.70, U6.70
GP81_SD_0_DAT3: U9.70, U10.70
GP81_SD_0_DAT4: U13.70, U14.70
GP81_SD_0_DAT5: U17.70, U18.70
GP81_SD_0_DAT6: U21.70, U22.70
GP81_SD_0_DAT7: U25.70, U26.70
GP81_SD_0_DAT8: U29.70, U30.70
GP81_SD_0_DAT9: U33.70, U34.70
GP81_SD_0_DAT10: U37.70, U38.70
GP82: U37.42, U38.42, U39.2
GP82_SD_0_DAT1: U5.64, U6.64
GP82_SD_0_DAT2: U2.64, U3.64
GP82_SD_0_DAT3: U9.64, U10.64
GP82_SD_0_DAT4: U13.64, U14.64
GP82_SD_0_DAT5: U17.64, U18.64
GP82_SD_0_DAT6: U21.64, U22.64
GP82_SD_0_DAT7: U25.64, U26.64
GP82_SD_0_DAT8: U29.64, U30.64
GP82_SD_0_DAT9: U33.64, U34.64
GP82_SD_0_DAT10: U37.64, U38.64
GP83: U37.34, U38.34, U39.3
GP83_SD_0_DAT1: U5.68, U6.68
GP83_SD_0_DAT2: U9.68, U10.68
GP83_SD_0_DAT3: U2.68, U3.68
GP83_SD_0_DAT4: U13.68, U14.68
GP83_SD_0_DAT5: U17.68, U18.68
GP83_SD_0_DAT6: U21.68, U22.68
GP83_SD_0_DAT7: U25.68, U26.68
GP83_SD_0_DAT8: U29.68, U30.68
GP83_SD_0_DAT9: U33.68, U34.68
GP83_SD_0_DAT10: U37.68, U38.68
GP84: U37.32, U38.32, U39.4
GP84_SD_CLK_FB: U2.44, U3.44
GP84_SD_CLK_FB1: U5.44, U6.44
GP84_SD_CLK_FB2: U9.44, U10.44
GP84_SD_CLK_FB3: U13.44, U14.44
GP84_SD_CLK_FB4: U17.44, U18.44
GP84_SD_CLK_FB5: U21.44, U22.44
GP84_SD_CLK_FB6: U25.44, U26.44
GP84_SD_CLK_FB7: U29.44, U30.44
GP84_SD_CLK_FB8: U33.44, U34.44
GP84_SD_CLK_FB9: U37.44, U38.44
GP85: U37.30, U38.30, U39.7
GP86: U37.28, U38.28, U39.8
GP87: U37.26, U38.26, U39.9
GP88: U37.25, U38.25
GP89: U37.24, U38.24, U39.10
GP109_SPI_2_CLK: U2.55, U3.55
GP109_SPI_2_CLK1: U5.55, U6.55
GP109_SPI_2_CLK2: U9.55, U10.55
GP109_SPI_2_CLK3: U13.55, U14.55
GP109_SPI_2_CLK4: U17.55, U18.55
GP109_SPI_2_CLK5: U21.55, U22.55
GP109_SPI_2_CLK6: U25.55, U26.55
GP109_SPI_2_CLK7: U29.55, U30.55
GP109_SPI_2_CLK8: U33.55, U34.55
GP109_SPI_2_CLK9: U37.55, U38.55
GP110_SPI_2_FS0: U2.53, U3.53
GP110_SPI_2_FS1: U5.53, U6.53
GP110_SPI_2_FS2: U9.53, U10.53
GP110_SPI_2_FS3: U13.53, U14.53
GP110_SPI_2_FS4: U17.53, U18.53
GP110_SPI_2_FS5: U21.53, U22.53
GP110_SPI_2_FS6: U25.53, U26.53
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

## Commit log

2014-08-09 initial commit with template renamed.
    [Mezzanine_GPIO_Breakout.brd, Mezzanine_GPIO_Breakout.sch]
2014-08-09 completed layout of GPIO Ready for review
    [Mezzanine_GPIO_Breakout.brd, Mezzanine_GPIO_Breakout.sch]
2014-08-09 added rev number to SCH
    [Mezzanine_GPIO_Breakout.sch]
2014-08-12 removed Edzzanine from name
    [Mezzanine_GPIO_Breakout.brd]
2014-09-23 added level shifters with the ability to select from vsys and 3.3v cleaned up copper pours changed name on board and files added DCIN pin cleaned up units of board.
    [GPIO_Block.brd, GPIO_Block.sch]
2014-09-25 file cleanup
    [GPIO_Block.brd, GPIO_Block.sch]
2014-10-01 corrected silk error CTS pin on UART was incorrectly numbered
    [GPIO_Block.brd]
2014-10-16 t/bRestrict between connector pads. (v10)
    [GPIO_Block.brd, GPIO_Block.sch]
2014-10-16 Re-routing 3.3v line
    [GPIO_Block.brd]
2014-10-17 Adding silk to bottom. Slight trace re-routes.
    [GPIO_Block.brd]
2014-10-17 adding thermal to staking pad
    [GPIO_Block.brd, GPIO_Block.sch]
2014-10-17 removed stray Bplace from Package
    [GPIO_Block.brd, GPIO_Block.sch]
2014-10-17 Ready for reds No changes No known to-do items
    [GPIO_Block.brd, GPIO_Block.sch]
2014-10-20 created v10 panels
    [GPIO_Block-GiantPanel-v10.brd, GPIO_Block-Panel-v10.brd]
2014-10-20 added Route Out for GP
    [GPIO_Block-GiantPanel-v10.brd]
2015-04-01 Updating README and directory file name
    [GPIO_Block-GiantPanel-v10.brd, GPIO_Block-Panel-v10.brd]

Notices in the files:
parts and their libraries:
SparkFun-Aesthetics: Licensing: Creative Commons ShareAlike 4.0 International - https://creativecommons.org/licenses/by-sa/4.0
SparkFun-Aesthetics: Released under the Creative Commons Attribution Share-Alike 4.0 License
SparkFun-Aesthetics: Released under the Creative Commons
